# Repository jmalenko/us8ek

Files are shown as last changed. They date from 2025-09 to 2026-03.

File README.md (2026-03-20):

# US8EK: Unibody Split 80% Ergo Keyboard

```
unibody split 80% ergo keyboard
───┬─── ──┬── ─┬─ ─┬──
   │      │    │   │
   │      │    │   └─── orthogonal key layout 
   │      │    └─────── Fn, arrow and navigation keys, no numpad
   │      └──────────── rotated halves
   └─────────────────── one piece
```

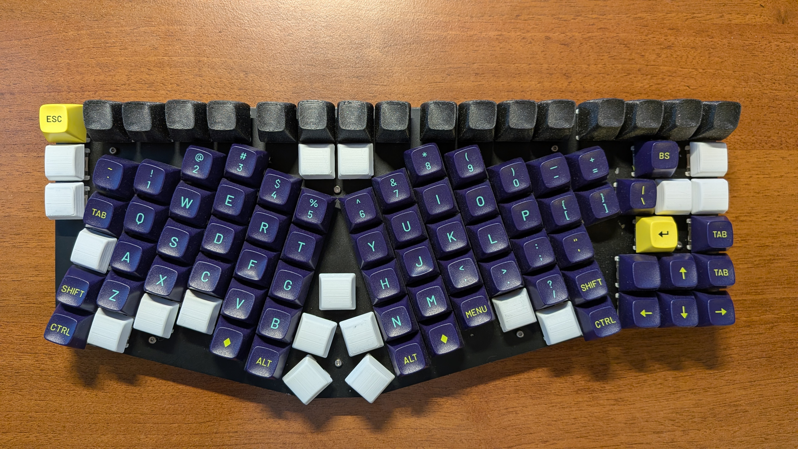
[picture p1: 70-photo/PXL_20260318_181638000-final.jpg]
Keyloard


**An ergonomic mechanical keyboard designed for developers and power users**

The perfect balance of familiarity and ergonomics with this innovative unibody split keyboard featuring:
- **Ergonomic design** - Matrix layout optimized for each hand
- **Single body construction** - No sliding or separation issues
- **Complete navigation cluster** - Dedicated arrows, modifiers, and function keys for seamless transition from standard keyboards
- **Fully open source** - Hardware and firmware available to the community

## Design Philosophy

Real-world usage analysis (by the author, Jaromír Malenko) revealed a striking truth: navigation keys dominate our daily keyboard interactions. Running [KeyboardFrequencies](https://github.com/PeterTheobald/KeyboardFrequencies) for one week showed navigation keys are used **14× more** than the most frequent alphanumeric key!

**Usage statistics:**
```
down:     11,952    (most used key!)
up:       10,320      
right:     7,115    
left:      6,239     
backspace: 2,723
...
a:           854    (most used letter)
```

This data confirms what many developers and content creators experience daily - we spend more time navigating code, file systems, and documents than typing new content. **US8EK prioritizes this reality.**

**Effortless hotkey access** - Complex shortcuts like IntelliJ's `Ctrl + Alt + F9` (Force Run to Cursor) remain natural and quick. No more layer juggling or muscle memory retraining.

**Dedicated function keys** - Essential F-keys are always accessible, supporting professional workflows from debugging to media control.

**Unibody meets ergonomics** - Enjoy the comfort of split design without the frustration of shifting halves or cable management between sections.

### Lessons from Real Experience

**Kyria insights:**
- ✅ Validated matrix layout comfort
- ✅ Confirmed need for dedicated navigation keys
- ❌ Two-piece instability (even 20cm tethering couldn't fully solve this)

**X-Bows learnings:**
- ✅ Appreciated familiar key arrangement
- ✅ Confirmed unibody preference
- ❌ Proprietary limitations (keycap compatibility, missing home/end keys)

**US8EK synthesis:** Combines the best aspects while addressing every pain point encountered.

## Technical Solution

### Design
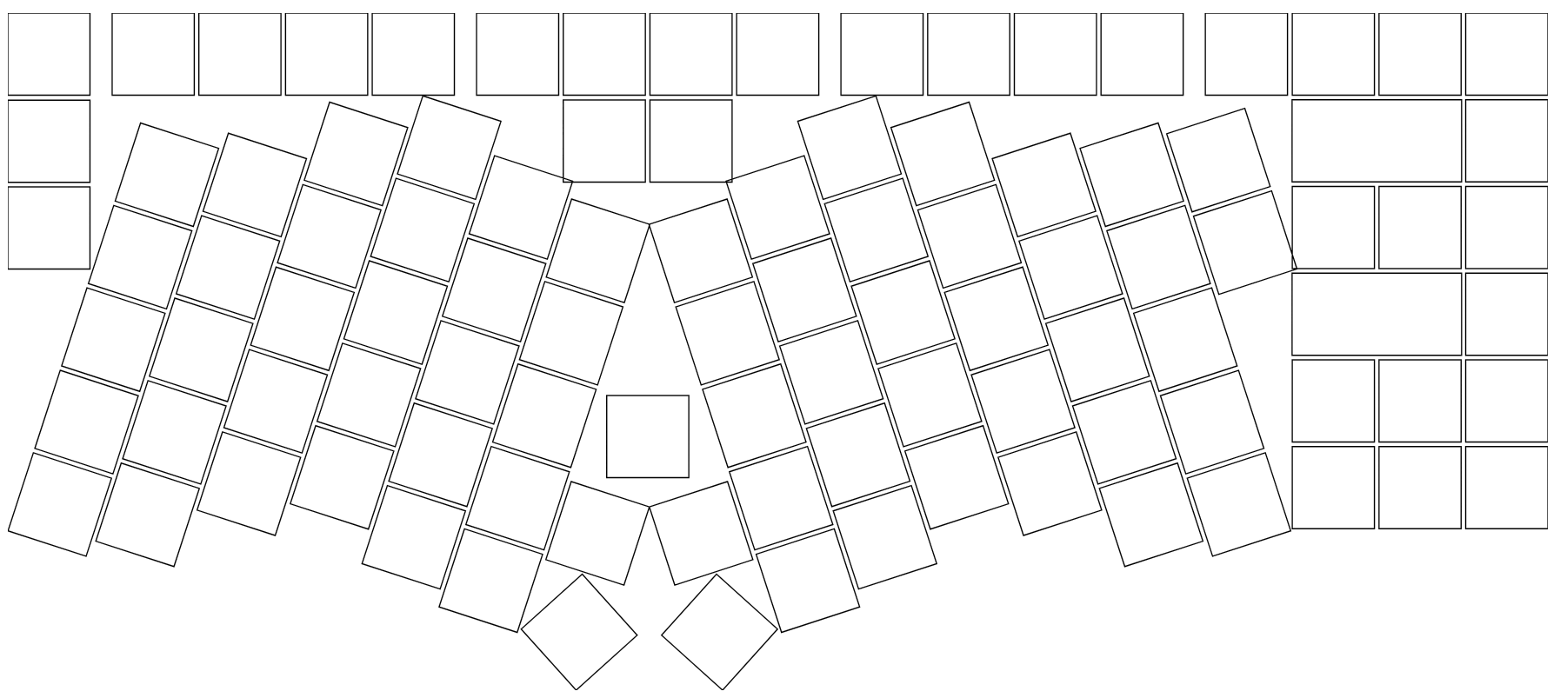
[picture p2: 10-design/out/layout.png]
Key layout
 generated in Ergogen

### Hardware Components
- **Controller:** [Frood RP2040](https://42keebs.eu/shop/parts/controllers/frood-rp2040-pro-micro-controller/) - has 25 I/O pins. The keyboard actually uses only 23 pins, so any Pro Micro microcontroller can be used.
- **Switches:** Glorious PC Gaming Race Gateron (120-pack); or any other switches
- **Diodes:** 1N4148 - get pack of 100 pieces
- **Wire:** 17 AWG = 1.04 mm² nicely fits between switch leg and stem
- **Keycaps:** MT3 profile - Ergonomic sculpting with premium feel; or any other keycaps. 101 pieces in total, some narrower keycaps are available in this project and must be 3d printed.
- **Plate:** Laser-cut steel. 1.5 mm thick.
- **Case:** 3D printed, PLA. 8 pieces of M2x12 (M2 screw, lenght 12 mm), 8 pieces of heat insert M2x4 (for M2 screw, length 4 mm).

### Build guide

1. Study **Primary guides** below. 

2. Get componenents.

   2.1. Laser cut the [plate](10-design/out/switch_plate_3dprint.dxf).

   2.2. Order hardare components.

3. Build - Solder it together.

   Actual wiring:

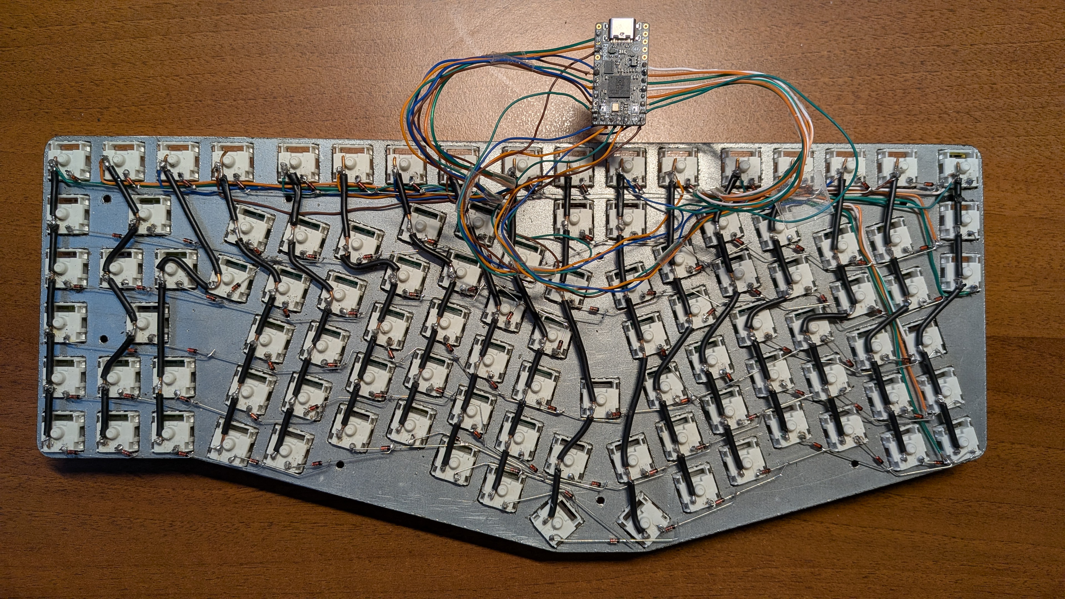
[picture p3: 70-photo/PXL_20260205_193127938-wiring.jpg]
Wiring
   

   Wiring plan:

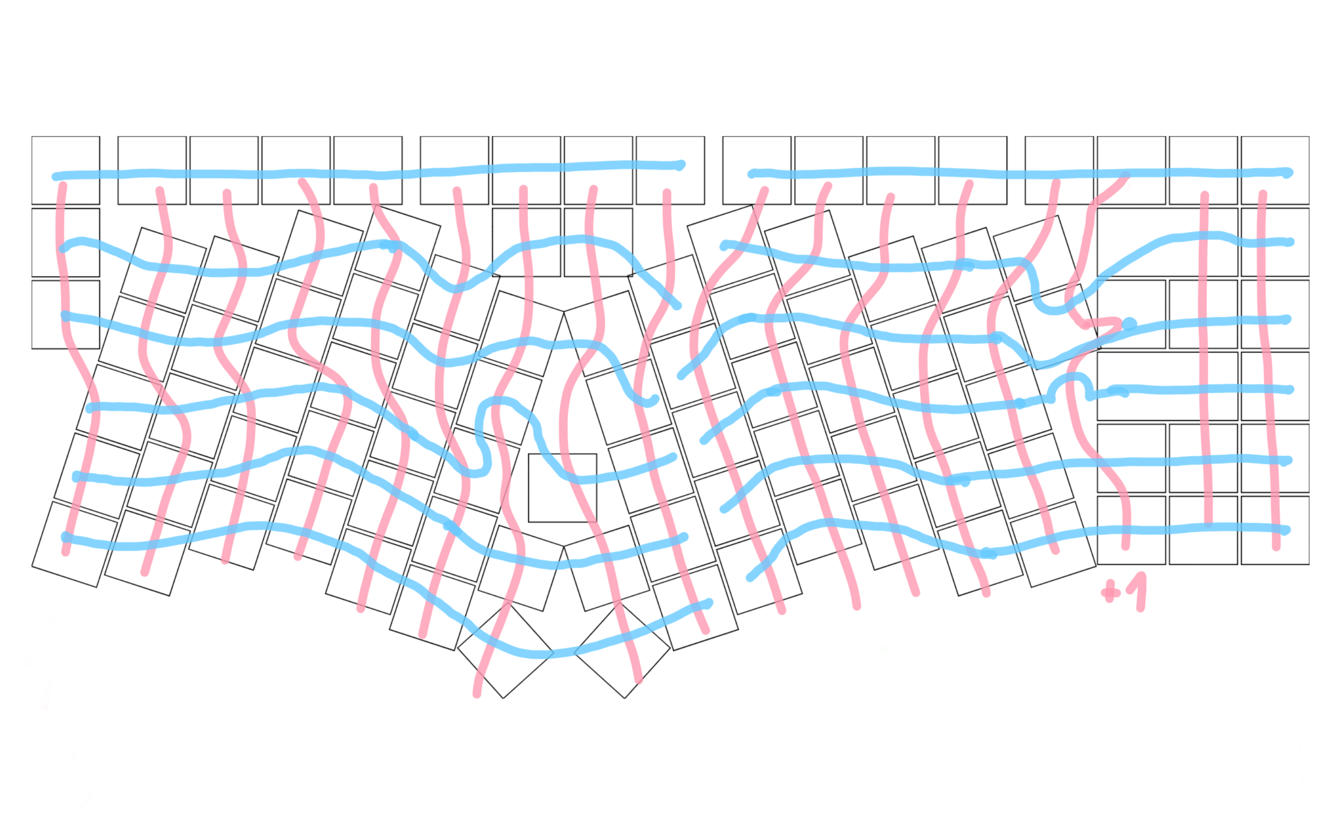
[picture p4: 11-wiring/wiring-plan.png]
Wiring plan
   

   - Q: Which columns/rows shall be soldered to which pin?

     A: You can use any reasonable pin (not power, ground or USB-C). If you wire it according to the following diagram, then you don't need to modify the configuration in `kb.py`.

     TODO Add diagram.

4. Configure microcontroller.

   4.1. Setup CircuitPython.

        Documentation and download are available at [https://circuitpython.org/board/42keebs_frood/](https://circuitpython.org/board/42keebs_frood/).

   4.2. Copy kmk & your configuration to the microcontroller.
        
        Copy [20-sw/20-kmk/*](20-sw/20-kmk) to root of your microcontroller. (So, there will be a *kmk* directory and *boot.py*, *main.py* and *kb.py* files in the root.)

5. Optional: Customize your configuration in *main.py*.
   
   See [kmk_firmware documentation](https://github.com/KMKfw/kmk_firmware/tree/main/docs/en). 

## Resources & Inspiration

**Primary guides**
- Let's Design A Keyboard With Ergogen:
  - [Part 1 - Units & Points](https://flatfootfox.com/ergogen-part1-units-points/),
  - [Part 2 - Outlines](https://flatfootfox.com/ergogen-part2-outlines/),
  - [Part 3 - PCB](https://flatfootfox.com/ergogen-part3-pcbs/),
  - [Part 4 - Offline Ergogen, External Footprints, & Cases](https://flatfootfox.com/ergogen-part4-footprints-cases/),
  - [Part 5 - KiCAD, Firmwares, & Assembly](https://flatfootfox.com/ergogen-part5-kicad-firmware-assembly/)

- [How to Build a Handwired Keyboard](https://www.youtube.com/watch?v=hjml-K-pV4E&t=554s) by Joe Scotto

- [Frood](https://github.com/piit79/Frood) microcontroller documentation

- [KMK](https://github.com/KMKfw/kmk_firmware)

**Research**
- Community inspiration for **wiring**. I did not want to use heatshrink and strip the wire; ale I wanter to use diode legs instead of a wire.
  - [3D printed and hand wired corne](https://www.reddit.com/r/HandwiredKeyboards/comments/1nthd3h/3d_printed_and_hand_wired_corne)
  - [4x10 Ortho Handwire](https://www.reddit.com/r/HandwiredKeyboards/comments/1o70lsv/4x10_ortho_handwire)
  - [Hex and Uf2 questions](https://www.reddit.com/r/HandwiredKeyboards/comments/1nns3z9/hex_and_uf2_questions)
  - [Reach - wireless split staggered running ZMK](https://www.reddit.com/r/HandwiredKeyboards/comments/1o72p64/reach_wireless_split_staggered_running_zmk)
  - [Second Handwire Complete](https://www.reddit.com/r/HandwiredKeyboards/comments/1kvkm4v/second_handwire_complete)
  - [Second Handwire Up and Running](https://www.reddit.com/r/HandwiredKeyboards/comments/1mdjikk/second_handwire_up_and_running/#lightbox)
  - [Final v4n build](https://www.reddit.com/r/HandwiredKeyboards/comments/1mm9syf/final_v4n_build)
  - [Built myself a handwired corne](https://www.reddit.com/r/HandwiredKeyboards/comments/1j9lmwk/built_myself_a_handwired_corne/#lightbox)
  - [Introducing the HellSplit!](https://www.reddit.com/r/HandwiredKeyboards/comments/1m4534o/introducing_the_hellsplit)
  - [First board I've Ever Designed / Handwired / 3D Printed [Open Source]](https://www.reddit.com/r/HandwiredKeyboards/comments/1lpn7hz/first_board_ive_ever_designed_handwired_3d)

- [Pro Micro & Fio V3 Hookup Guide](https://learn.sparkfun.com/tutorials/pro-micro--fio-v3-hookup-guide/hardware-overview-pro-micro)
- [nice!nano](https://nicekeyboards.com/docs/nice-nano/)

**Keyoboards**
- [X-Bows Nature](https://x-bows.com/products/x-bows-nature)

  X-Bows

- [Another custom hand wired board](https://www.reddit.com/r/MechanicalKeyboards/comments/1fskfku/another_custom_hand_wired_board/)
  
  Another custom hand wired board

## Project Plan

### Future Enhancements
- [ ] Wiring diagram
- [ ] Add a key next to backspace (Currently, backspace is a 2u key and we can add one more key to the layout)
- [ ] Ask the original aouthor of MT3 keycaps to make the taller Fn keycaps and shorter 1u spacebar. (The author published STL files of some of these, but modifying them is complicated work. Moreover, modifications of STL are not ideal: The taller keycaps seems ok, but the stem start higher than required. The shorter keycaps are complicated because there is not enough space for the switch. That's when a simple scaling in the vertical direction is used.)

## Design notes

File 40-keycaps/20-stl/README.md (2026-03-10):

In this project, we modified the original MT3 keycaps to suite our needs.

The original, wtored in *MT3-row0.stl*, has [Attribution-ShareAlike](https://creativecommons.org/licenses/by-sa/4.0/) license.

Our modification in *MT3-row0 tall.stl* makes the key taller by 30%, so it's practical for Fn row.

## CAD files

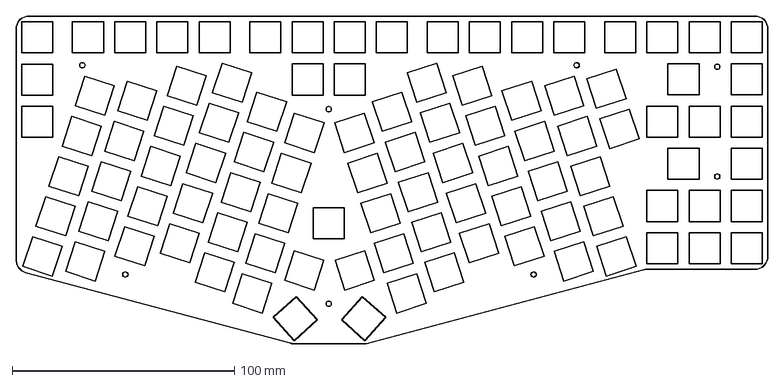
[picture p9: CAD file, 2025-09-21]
10-design/out/switch_plate_3dprint.dxf
338.5 x 147.6 mm

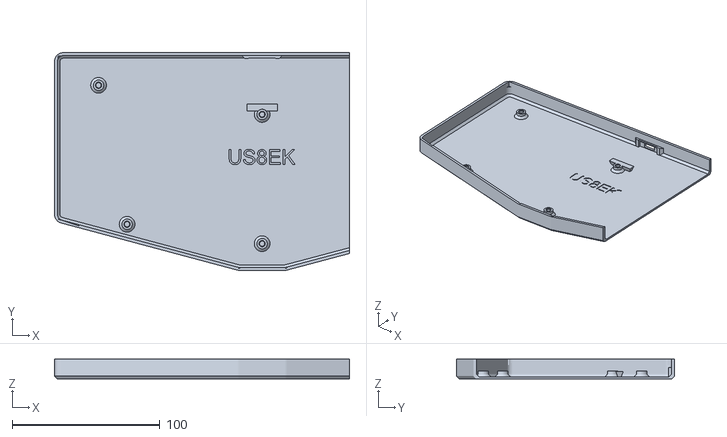
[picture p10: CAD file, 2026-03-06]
30-case/20-stl/Case left.stl
200.0 x 147.6 x 13.4

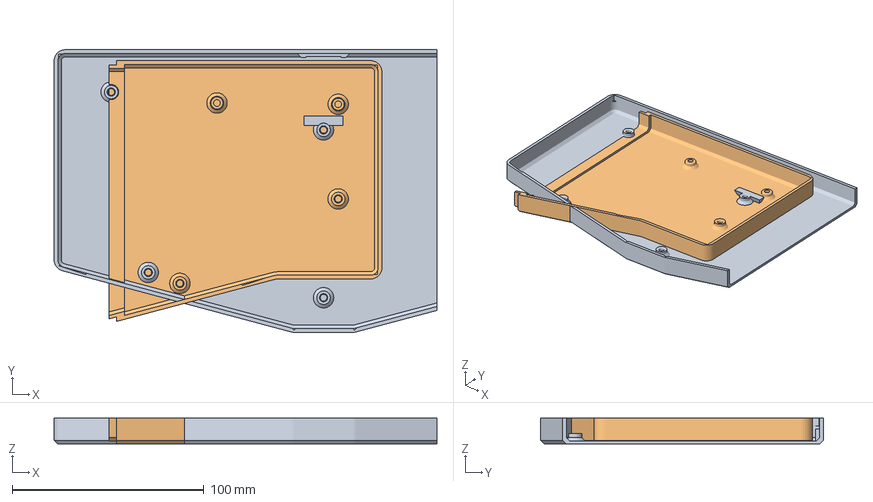
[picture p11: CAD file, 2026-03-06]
30-case/30-slicer/Case.3mf
200.0 x 147.6 x 13.4 mm
Case left.stl
Case right 2026-03-01.stl

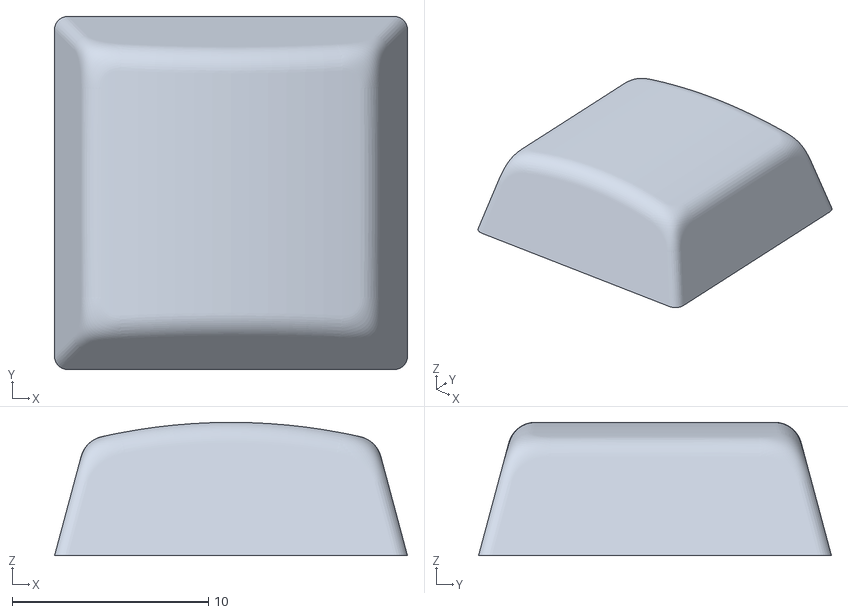
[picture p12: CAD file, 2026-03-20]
40-keycaps/20-stl/JM keycap short.stl
18.0 x 18.0 x 6.80

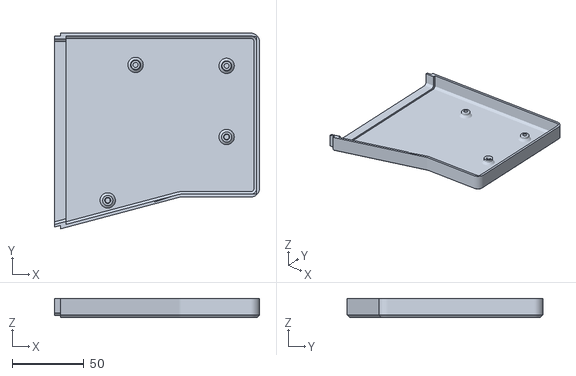
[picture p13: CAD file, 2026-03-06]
30-case/20-stl/Case right.stl
142.5 x 136.2 x 13.4

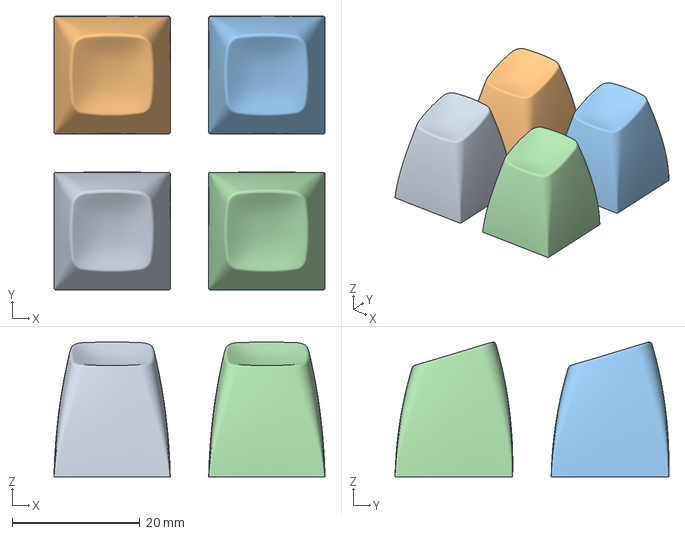
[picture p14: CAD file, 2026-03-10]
40-keycaps/30-slicer/MT3 modified.3mf
42.4 x 42.9 x 21.1 mm

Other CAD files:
40-keycaps/30-slicer/JM keycap short.3mf
30-case/10-model/US8EK.f3d
40-keycaps/10-model/JM keycap short.f3d

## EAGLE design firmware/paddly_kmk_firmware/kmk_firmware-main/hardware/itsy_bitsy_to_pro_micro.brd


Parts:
FRAME2: FRAME-LETTER; CREATIVE_COMMONS
JP1: HEADER-1X570MIL; 1X05_ROUND_70
JP2, JP4: HEADER-1X14; 1X14_ROUND70
JP3, JP5: M12PTH; 1X12

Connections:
!RESET: JP3.3, JP4.14
+3V3: JP4.13
A0: JP3.5, JP4.10
A1: JP3.6, JP4.9
A2: JP3.7, JP4.8
A3: JP3.8, JP4.7
A4: JP3.9, JP4.6
A5: JP3.10, JP4.5
AREF: JP4.12
D2: JP4.1
D3: JP1.4
D4: JP1.5
D5_5V: JP2.10
D7: JP2.9, JP5.1
D9: JP2.8, JP5.2
D10: JP2.7, JP5.3
D11: JP2.6, JP5.4
D12: JP2.5, JP5.5
D13: JP2.4, JP5.6
EN: JP1.1
GND: JP2.2, JP3.2, JP5.9, JP5.10
MISO: JP4.2
MOSI: JP3.12, JP4.3
RAW_PM: JP3.1
RX_D0: JP2.14, JP5.11
SCK: JP3.11, JP4.4
SCL: JP2.11, JP5.7
SDA: JP2.12, JP5.8
SWCLK: JP1.3
SWDIO: JP1.2
TX_D1: JP2.13, JP5.12
VBAT: JP2.1
VBUS: JP2.3, JP3.4
VHI: JP4.11

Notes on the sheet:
TX0/PD3->TX RX1/PD2->RX GND->GND GND->GND 2/PD1->SDA 3/PD0->SCL 4/PD4->13 5/PC6->12 6/PD7->11 7/PE6->10 8/PB4->9 9/PB5->7
OLD
Raw-> GND->GND RST->RST VCC->USB A3/PF4->A0 A2/PF5->A1 A1/PF6->A2 A0/PF7->A3 15/PB1->A4 14/PB3->A5 16/PB2->SCK 10/PB6->MOSI
Bryan Siepert



Board: 2 copper layers, 35.8 x 20.7 mm, 6 parts (2 on the bottom side), 21 nets.

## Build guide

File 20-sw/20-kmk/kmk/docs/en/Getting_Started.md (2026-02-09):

# Getting Started
> Life was like a box of chocolates. You never know what you're gonna get.

KMK is a keyboard focused layer that sits on top of [CircuitPython](https://circuitpython.org/). As such, it should work with most [boards that support CircuitPython](https://circuitpython.org/downloads). KMK requires CircuitPython version 7.3 or above.
Known working and recommended devices can be found in the [list of officially supported microcontrollers](Officially_Supported_Microcontrollers.md)

## TL;DR Quick start guide
> To infinity and beyond!
1. [Install CircuitPython version 7.3 or higher on your board](https://learn.adafruit.com/welcome-to-circuitpython/installing-circuitpython). With most boards, it should be as easy as drag and dropping the firmware on the drive
2. Get an up to date [copy of KMK](https://github.com/KMKfw/kmk_firmware/archive/refs/heads/main.zip) from the main branch 
3. Unzip it and copy the KMK folder and the boot.py file at the root of the USB drive corresponding to your board (often appearing as CIRCUITPY)
4. Create a new *code.py* or *main.py* file in the same root directory (same level as boot.py) with the example content hereunder: 

***IMPORTANT:*** adapt the GP0 / GP1 pins to your specific board !

```
print("Starting")

import board

from kmk.kmk_keyboard import KMKKeyboard
from kmk.keys import KC
from kmk.scanners import DiodeOrientation

keyboard = KMKKeyboard()

keyboard.col_pins = (board.GP0,)
keyboard.row_pins = (board.GP1,)
keyboard.diode_orientation = DiodeOrientation.COL2ROW

keyboard.keymap = [
    [KC.A,]
]

if __name__ == '__main__':
    keyboard.go()
```

5. With a wire / paperclip / whatever, connect the pins you selected for col_pin and row_pin together.

feather and keeboar example pins


6. If it prints the letter "a" (or a "Q" or ... depending on your keyboard layout), you're done!

## Now that you're up and running, you may want to go further...
> This is your last chance. After this, there is no turning back. You take the blue pill—the story ends, you wake up in your bed and believe whatever you want to believe. You take the red pill—you stay in Wonderland, and I show you how deep the rabbit hole goes. Remember: all I'm offering is the truth. Nothing more.

### You're extremely lucky and you have a fully supported keyboard
If your keyboard and microcontroller are officially supported, simply visit the page for your files, and dropping them on the root of the "flash drive".
Those pages can be found in the repositories [boards folder](https://github.com/KMKfw/kmk_firmware/tree/master/boards).
You will need the `kb.py` and `main.py`. If you need more detailed instructions on how to customize the configuration settings and key mappings, please refer to the [config and keymap](config_and_keymap.md) documentation.

### You've got another, maybe DIY, board and want to customize KMK for it  
First, be sure to understand how your device work, and particularly its specific matrix configuration. You can have a look at [how key matrices work](http://pcbheaven.com/wikipages/How_Key_Matrices_Works/) or read the [guide](https://docs.qmk.fm/#/hand_wire) provided by the QMK team for handwired keyboards
Once you've got the gist of it:
- To start customizing your `code.py`/`main.py` file, please refer to the [config and keymap](config_and_keymap.md) and [keys](keys.md) files respectively, which provide detailed instructions on how to modify the configuration settings and key mappings.
- There's a [reference](keycodes.md) of the available keycodes
- [International](international.md) extension adds keys for non US layouts and [Media Keys](media_keys.md) adds keys for ... media

And to go even further:
- [Macros](macros.md) are used for sending multiple keystrokes in a single action
- [Layers](layers.md) can transform the whole way your keyboard is behaving with a single touch
- [HoldTap](holdtap.md) allow you to customize the way a key behaves whether it is tapped or hold, and [TapDance](tapdance.md) depending on the number of times it is pressed

Want to have fun features such as RGB, split keyboards and more? Check out what builtin [modules](modules.md) and [extensions](extensions.md) can do!
You can also get ideas from the various [user examples](https://github.com/KMKfw/kmk_firmware/tree/master/user_keymaps) that we provide and dig into our [documentation](README.md).

### Pre-compiling KMK for faster boot times or microcontrollers with limited flash

There are two options:
1. To compile KMK yourself you'll need to download and install the [compatible mpy-cross](https://adafruit-circuit-python.s3.amazonaws.com/index.html?prefix=bin/mpy-cross/)
  for your Operating System. Don't forget to add it to your PATH, test by running `mpy-cross` from a shell (Powershell, Bash, Fish, etc). Once that's set up, run either `make compile` (if you have `make`) or `python util/compile.py`to generate the `.mpy` versions of KMK files. Then copy the whole compiled `kmk/` directory to your keyboard.

There are even more compile and copy make targets.
Power user can compile KMK and additional libraries, and then load the bytecode and keyboard code
onto a keyboard in one go:
```sh
make compile copy-compiled copy-board MPY_SOURCES='kmk/ lib/' BOARD='boards/someboard' MOUNTPOINT='/media/user/someboard'
```

2. To download a pre-compiled KMK go to [Actions > Build on the KMK GitHub project page](https://github.com/KMKfw/kmk_firmware/actions/workflows/compile.yml),
  click on the latest build, and you'll find the download link at the bottom of the page under Artifacts. Unzip the download and place the contents in the `kmk/` directory on your keyboard.

On certain microcontrollers that will still not be enough of a size reduction to
fit all of KMK onto the flash (nice!nano for example).
You can remove any optional parts of KMK you aren't using.
Start by skipping `kmk/extensions`, `kmk/modules`, and `kmk/quickpin` and adding in only the files under those paths used in your keyboard (i.e. files that are imported in your `main.py` or `kb.py`).

## Additional help and support
> Roads? Where we're going we don't need roads.

In case you need it, debugging help can be found on the [debugging](debugging.md) page.

For asynchronous support and chatter about KMK, [join our Zulip
community](https://kmkfw.zulipchat.com)!

If you ask for help in chat or open a bug report, if possible
make sure your copy of KMK is up-to-date.
In particular, swing by the Zulip chat *before* opening a GitHub Issue about
configuration, documentation, etc. concerns.

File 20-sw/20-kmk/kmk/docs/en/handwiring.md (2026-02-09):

# Handwire keyboards
This guide will not talk about the physical wiring. Check out our 
[recommended microcontrollers](Officially_Supported_Microcontrollers.md) and 
follow this amazing [hand wiring guide](https://docs.qmk.fm/#/hand_wire). That 
guide can be followed until you are setting up the firmware. After wiring the 
keyboard, you can refer to our [porting guide](porting_to_kmk.md)

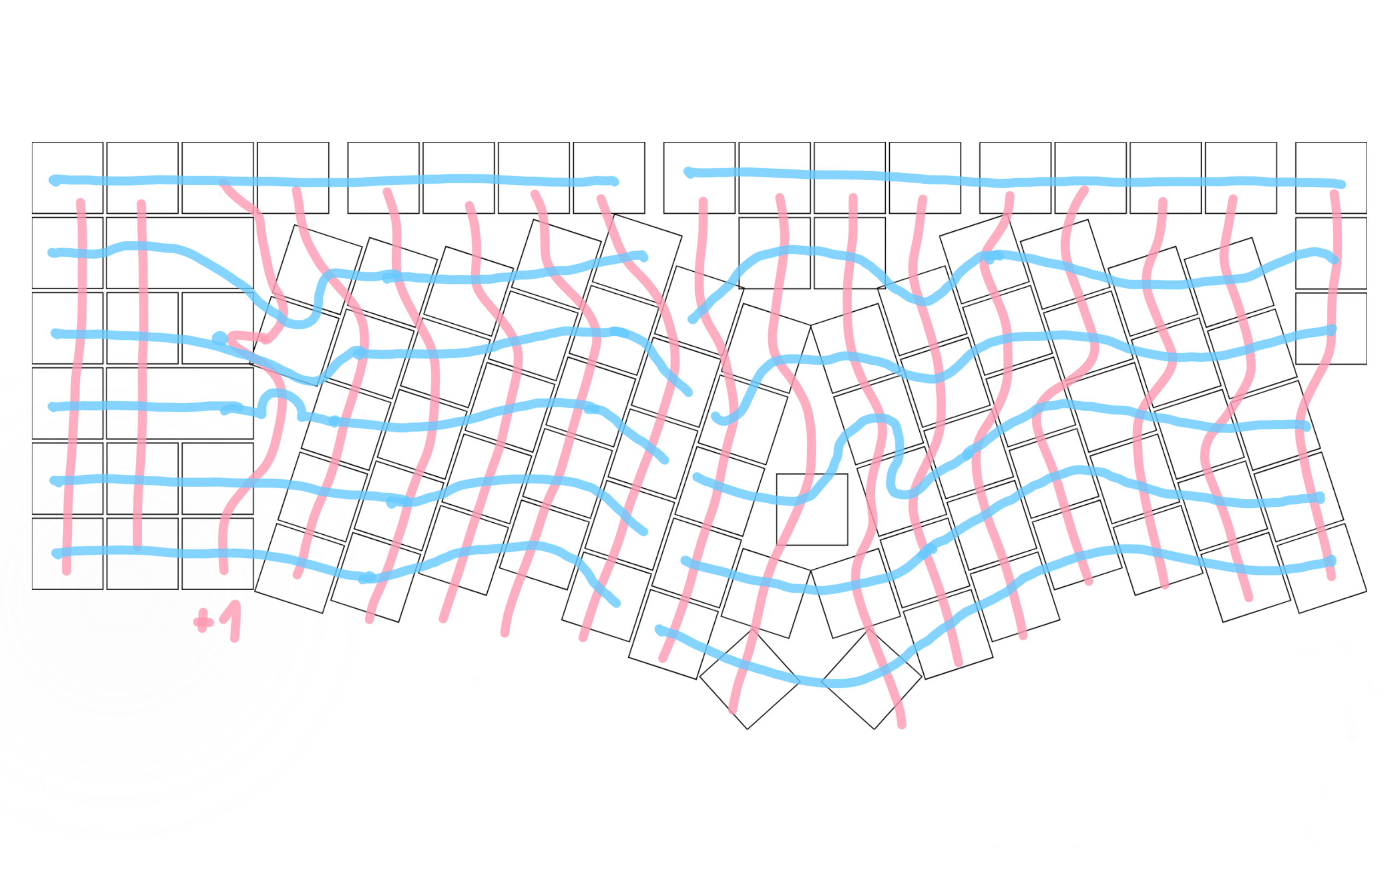
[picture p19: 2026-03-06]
11-wiring/wiring-plan-flipped-for-actual-wiring.tiff

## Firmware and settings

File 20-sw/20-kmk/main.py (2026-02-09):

from kb import KMKKeyboard

from kmk.keys import KeyboardKey, make_key
from kmk.extensions.media_keys import MediaKeys
from kmk.keys import KC

keyboard = KMKKeyboard()

keyboard.extensions.append(MediaKeys())

APP_KEY = make_key(names=('APP', 'MENU'), constructor=KeyboardKey, code=101)

# fmt: off
keyboard.keymap = [
    [  # BASE
        KC.ESC,  KC.F1,   KC.F2,   KC.F3,   KC.F4,   KC.F5,   KC.F6,                                       KC.F7,   KC.F8,   KC.F9,   KC.F10,  KC.F11,  KC.F12,      KC.PSCR, KC.SLCK, KC.PAUS, KC.INS,
        KC.BRIU ,KC.GRV,  KC.N1,   KC.N2,   KC.N3,   KC.N4,                     KC.VOLD, KC.VOLU,                   KC.N7,   KC.N8,   KC.N9,   KC.N0,   KC.MINS,     KC.EQL,  KC.RBRC, KC.BSPC, KC.MUTE,
        KC.BRID, KC.TAB,  KC.Q,    KC.W,    KC.E,    KC.R ,            KC.N5,                     KC.N6,   KC.Y,    KC.U,    KC.I,    KC.O,    KC.P,    KC.LBRC,              KC.BSLS, KC.F18,KC.HOME,
                 KC.CAPS, KC.A,    KC.S,    KC.D,    KC.F,    KC.G,    KC.T,    KC.MPLY,                   KC.H,    KC.J,    KC.K,    KC.L,    KC.SCLN, KC.QUOT,                       KC.ENT,  KC.END, 
                 KC.LSFT, KC.Z,    KC.X,    KC.C,    KC.V,    KC.B,             KC.MPRV, KC.MNXT,          KC.N,    KC.M,    KC.COMM, KC.DOT,  KC.SLSH, KC.RSFT,              KC.PGUP, KC.UP,   KC.PGDN,
                 KC.LCTL, KC.F13,  KC.F14,  KC.F15,  KC.LGUI, KC.LALT,          KC.SPC,  KC.ENT,           KC.RALT, KC.RGUI, KC.APP,  KC.F16,  KC.F17,  KC.RCTL,              KC.LEFT, KC.DOWN, KC.RGHT
    ],
]
# fmt: on

if __name__ == '__main__':
    keyboard.go()

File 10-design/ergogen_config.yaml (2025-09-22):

# Jaromir's keyboard
# Motivation / requirements:
# - stagger and thumkeys like Kyria
# - monoblock, Fn and arrow kayes like X-Bows
# - for ergo beginners => with num row like normal keyboard
units:

  # u unit provides a quick reference to the MX switch's 19mm
  # U represents 19.05mm for keycaps that need a bit more breathing room
  # cx and cy to reference the 18mm width and 17mm height of Choc keys

  # Constants
  choc_cap_x: 17.5
  choc_cap_y: 16.5
 
  choc_plate_thickness: 1.2
  mx_plate_thickness: 1.5
 
  # Parameters
  kx: U
  ky: U
  rotation: 18 # the angle between the left and right side is double this value

  # Case
  plate_thickness: mx_plate_thickness
  height_inner: 4
  height_total: height_inner + 2 * plate_thickness

  wall_thickness: 1
  screw_radius: 1 # M2 screw
  
  # Threaded screw inserts.
  # They're 3.2mm wide, and 3mm tall. All you need to do to add them to your design is create a hole that's 3mm in diameter and 3mm tall. Then you use a soldering iron to warm up the screw insert and melt the last 0.2mm of plastic.
  nut_inner_radius: 1.5
  nut_outer_radius: nut_inner_radius + 1.6
  nut_height_real: 3
  nut_height: nut_height_real + 0.5

  hole_radius: screw_radius + 0.2
  
  # To check that that switch cutouts don't overlap with threaded screw inserts, use:
  # hole_radius: nut_outer_radius
points:
  zones:
    matrix:
      columns:
        outer:
        pinky:
          key.stagger: 0.2ky
        ring:
          key.stagger: 0.7ky
        middle:
          key.stagger: 0.4ky
        index:
          key.stagger: -0.4ky
        inner:
          key.stagger: -0.2ky
      rows:
        mod:
        bottom:
        home:
        top:
        num:
    thumb:
      anchor:
        ref: matrix_inner_mod
        shift: [1.15kx, -0.25ky]
      columns:
        x:
          key.splay: -30
      rows:
        x:
    extra_center_sym:
      anchor:
        ref: matrix_inner_bottom
        shift: [kx, -0.1ky]
      columns:
        x:
      rows:
        x:
    func:
      key.asym: left
      anchor:
        ref: matrix_outer_num
        shift: [-1.72kx, 0.9ky] # Ensure: Gap between F6 and F7 is centered. (This is done by modifying 1st parameter.)
        rotate: rotation
      columns:
        esc:
        f1:
          key.spread: 1.2kx
        f2:
        f3:
        f4:
        f5:
          key.spread: 1.2kx
        f6:
        f7:
        f8:
        f9:
          key.spread: 1.2kx
        f10:
        f11:
        f12:
    nav:
      key.asym: left
      anchor:
        ref: func_f12
        # Design: top row is aligned with Fn row
        shift: [2.2kx, -5ky + 5*0.05] # Workaround: correction "+ 5*0.05" is there to align the top-most row. This seems like an erogen bud.
      columns:
        left:
          rows:
            home:
              width: 1.95kx
              shift: [0.5kx, 0]
            top:
              shift: [-0.5kx, 0]
            num:
              width: 1.95kx
              shift: [0.5kx, 0]
            fn:
              shift: [-0.5kx, 0]
        middle:
          rows.home.skip: true
          rows.num.skip: true
        right:
      rows:
        mod:
        bottom:
        home:
        top:
        num:
        fn:
    extra_left:
      key.asym: left
      anchor:
        ref: func_esc
        shift: [0, -2*ky]
      columns:
        x:
      rows:
        x:
        y:
    extra_right1: # -, [ keys, rotated
      key.asym: left
      anchor:
        ref: func_f12
        shift: [1.45kx, -6.53ky] # Remember cutout for usb connector
      columns:
        x:
      rows:
        x:
        y:
      rotate: rotation
    extra_right2: # F13
      key.asym: left
      anchor:
        ref: func_f12
        shift: [1.2kx, 0ky]
      columns:
        x:
      rows:
        x:
    extra_center_asym1:
      key.asym: left
      anchor:
        ref: func_f6
        shift: [0.5kx, -4.4ky]
      columns:
        x:
      rows:
        x:
    extra_center_asym2:
      key.asym: left
      anchor:
        ref: func_f6
        shift: [0kx, -1ky]
      columns:
        x:
        y:
      rows:
        x:
  rotate: -rotation
  mirror:
    ref: matrix_inner_home
    distance: 46
outlines:
  # Pure key outline.
  _raw:
    - what: rectangle
      where: true
      size: [kx+2, ky+2]
  # Key outlines with 0.5mm removed to show key overlaps.
  _keys:
    - what: rectangle
      where: true
      size: [kx-0.5, ky-0.5]
  # PCB board outline.
  board:
    - what: polygon
      operation: stack
      points:
        - ref: func_esc
          shift: [-0.5kx, 0.5ky]
        - ref: func_esc
          shift: [-0.5kx, -5.5ky]
#        - ref: func_f1
#          shift: [-0.4kx, -5.85ky]
#        - ref: func_f1
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

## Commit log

2024-11-22 Case - top with wall, bottom, without mounting holes
2024-11-23 Mounting holes
2024-11-26 Switch plate for 3d print
    [switch_plate_3dprint.dxf]
2025-09-21 Hole at top in center
2025-09-21 Two holes by nav block. For first laser cutting.
    [switch_plate_3dprint-2025-09-21.dxf]
2025-09-22 Smaller fillet. This will be the 1st laser cut.
    [switch_plate_3dprint-2025-09-22.dxf, switch_plate_3dprint.dxf]
2026-02-09 Before repo polishing
    [itsy_bitsy_to_pro_micro.brd, itsy_bitsy_to_pro_micro.sch, kmkpython_ref.tsv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]
2026-02-09 Big consolidation
    [itsy_bitsy_to_pro_micro.brd, itsy_bitsy_to_pro_micro.sch, kmkpython_ref.tsv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]
2026-03-06 Parts for case
2026-03-06 Improvements to case after print
    [Case left.stl, Case right.stl, Case.3mf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]
2026-03-10 Photos with case
2026-03-10 Tall keycap
    [MT3 modified.3mf]
2026-03-11 Show wiring plan
2026-03-20 Shot keycap
    [JM keycap short.3mf, JM keycap short.f3d, JM keycap short.stl]

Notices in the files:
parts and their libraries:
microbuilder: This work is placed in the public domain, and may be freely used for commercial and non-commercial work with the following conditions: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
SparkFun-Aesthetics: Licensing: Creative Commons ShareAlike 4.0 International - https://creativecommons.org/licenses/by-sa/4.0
